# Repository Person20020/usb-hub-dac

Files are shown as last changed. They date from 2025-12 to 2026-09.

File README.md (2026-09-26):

# USB Hub / DAC

> [!NOTE]
> The design has a 22 ohm resistor across the DAC's crystal (I have no clue why I did that) but it should be 1M. It also worked fine just taking the 22 ohm resistor off and leaving it empty.

A simple USB hub with 3 USB C outputs and a built in DAC for a 3.5mm audio output. It uses a SL2.1a USB hub controller and a PCM2902 DAC. 






USB Hub DAC PCB

## PCB
The PCB is designed to be mounted into the case using four M2x6mm screws into the four printed standoffs that use heat set inserts. The mute button is mounted on the top of the PCB and the case has a built in flexing tab that is used as a push button.

usb-hub-dac pcb

Layout



Schematic



## Parts

| Part | Quantity | LCSC # | Price (each) | Total price | Link |
| --- | --- | --- | --- | --- | --- |
| PCM 2902 | 1 | C2651869  | $15.0753 | $15.0753 | [Link](https://www.lcsc.com/product-detail/C2651869.html)  |
| SL2.1a | 1 | C192893 | $0.2259 | $1.13 (5 MOQ) | [Link](https://www.lcsc.com/product-detail/C192893.html) |
| USBLC6-2SC6 | 4 | C2827654  | $0.0387 | $0.39 (10 MOQ) | [Link](https://www.lcsc.com/product-detail/C2827654.html)  |
| PJ-320D 3.5mm TRRS Jack | 1 | C431535 | $0.0483 | $0.48 (10 MOQ) | [Link](https://www.lcsc.com/product-detail/C431535.html) |
| GCT_USB4110 USB C Port | 4 | C5143397  | $1.8037 | $7.21 | [Link](https://www.lcsc.com/product-detail/C5143397.html)  |
| 56k ohm 0805 Resistors | 6 | C2907336  | $0.0014 | $0.14 (100 MOQ)  | [Link](https://www.lcsc.com/product-detail/C2907336.html)  |
| 5.1k ohm 0805 Resistors | 2 | C2930296  | $0.0013 | $0.13 (100 MOQ)  | [Link](https://www.lcsc.com/product-detail/C2930296.html)  |
| 1.5k ohm 0805 Resistors | 1 | C2907216  | $0.0017 | $0.17 (100 MOQ)  | [Link](https://www.lcsc.com/product-detail/C2907216.html)  |
| 2.2 ohm 0805 Resistors | 1 | C2933402  | $0.0023 | $0.23 (100 MOQ)  | [Link](https://www.lcsc.com/product-detail/C2933402.html)  |
| 22 ohm 0805 Resistors | 3 | C2907310  | $0.0014 | $0.014 (100 MOQ) | [Link](https://www.lcsc.com/product-detail/C2907310.html)  |
| 10k ohm 0805 Resistors | 3 | C2930231  | $0.0012 | $0.012 (100 MOQ) | [Link](https://www.lcsc.com/product-detail/C2930231.html)  |
| 10uF Radial D4mm L8mm P1.5mm Capacitors | 4 | C36914040 | $0.0402 | $0.2 (5 MOQ) | [Link](https://www.lcsc.com/product-detail/C36914040.html) |
| 10uF 0805 Capacitors | 6 | C1713 | $0.0088 | $0.18 (20 MOQ) | [Link](https://www.lcsc.com/product-detail/C1713.html) |
| 1uF 0805 Capacitors | 3 | C28323 | $0.0092 | $0.18 (20 MOQ) | [Link](https://www.lcsc.com/product-detail/C28323.html) |
| 10pF 0805 Capacitors | 2 | C41361255 | $0.0045 | $0.45 (100 MOQ)  | [Link](https://www.lcsc.com/product-detail/C41361255.html) |
| 6mm Push Button | 1 | C42416249 | $0.0196 | $0.39 (20 MOQ) | [Link](https://www.lcsc.com/product-detail/C42416249.html) |
| 12 MHz Crystal | 2 | C16369 | $0.0834 | $0.42 (5 MOQ) | [Link](https://www.lcsc.com/product-detail/C16369.html) |

Total cost: \~$26.80 + PCB (\~$2)

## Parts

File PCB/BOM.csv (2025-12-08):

Id | Designator | Footprint | Quantity | Designation | Supplier and ref
1 | U2,U5,U4,U3 | SOT-23-6 | 4 | USBLC6-2SC6
2 | J4,J3,J1,J2 | USB_C_Receptacle_GCT_USB4110 | 4 | USB_C_Receptacle_USB2.0_16P
3 | R4,R6,R2,R3,R7,R5 | R_0805_2012Metric_Pad1.20x1.40mm_HandSolder | 6 | 56k
4 | C12,C7,C8,C11 | CP_Radial_D4.0mm_P1.50mm | 4 | 10uF
5 | C5,C6,C1,C4,C3,C2 | C_0805_2012Metric_Pad1.18x1.45mm_HandSolder | 6 | 10uF
6 | U1 | SSOP-28_5.3x10.2mm_P0.65mm | 1 | PCM2902
7 | R1,R10,R11 | R_0805_2012Metric_Pad1.20x1.40mm_HandSolder | 3 | 10k
8 | C9,C10 | C_0805_2012Metric_Pad1.18x1.45mm_HandSolder | 2 | 10pF
9 | R17 | R_0805_2012Metric_Pad1.20x1.40mm_HandSolder | 1 | 1.5k
10 | J5 | Jack_3.5mm_PJ320D_Horizontal | 1 | AudioJack4
11 | R8,R9 | R_0805_2012Metric_Pad1.20x1.40mm_HandSolder | 2 | 5.1k
12 | R16 | R_0805_2012Metric_Pad1.20x1.40mm_HandSolder | 1 | 2.2
13 | R13,R15,R14 | R_0805_2012Metric_Pad1.20x1.40mm_HandSolder | 3 | 22
14 | C15,C13,C14 | C_0805_2012Metric_Pad1.18x1.45mm_HandSolder | 3 | 1uF
15 | SW1 | SW_PUSH_6mm_H7.3mm | 1 | Mute_button
16 | IC1 | STC_SOP-16_3.9x9.9mm_P1.27mm | 1 | SL2.1A
17 | Y2,Y1 | Crystal_HC49-4H_Vertical | 2 | 12MHz

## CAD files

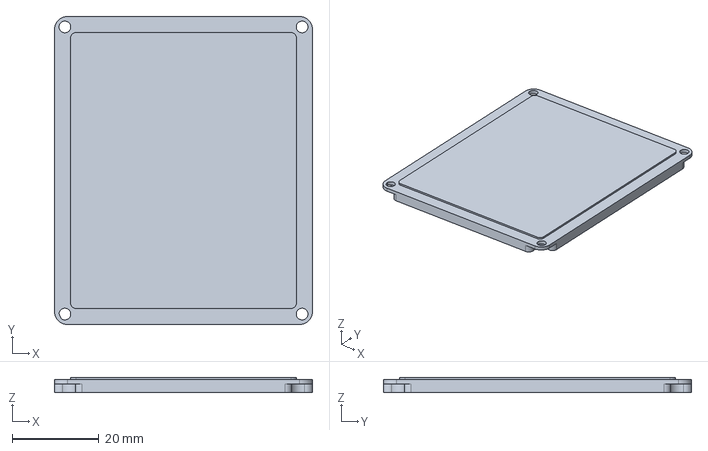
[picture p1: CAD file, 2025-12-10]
CAD/USB Hub DAC Case -- Base.step
59.5 x 71.0 x 3.50 mm

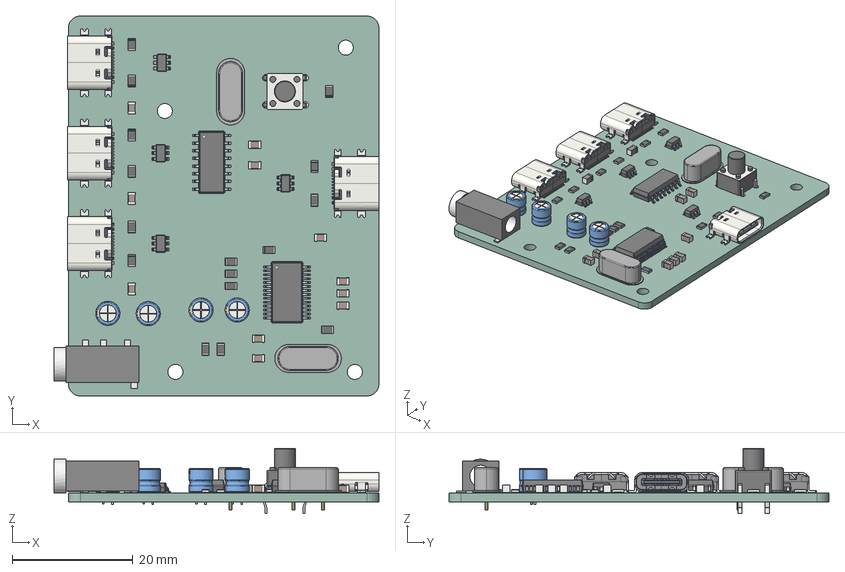
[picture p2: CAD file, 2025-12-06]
PCB/PCB.step
53.9 x 63.0 x 10.8 mm
SOT-23-6 x 4
USB_C_Receptacle_GCT_USB4110-xx-A_16P_TopMnt_Horizontal x 4
R_0805_2012Metric x 16
CP_Radial_D4.0mm_P1.50mm x 4
C_0805_2012Metric x 11
SSOP-28_5.3x10.2mm_P0.65mm
TRRS20153
SW_PUSH_6mm_H7.3mm
SOP-16_4.4x10.4mm_P1.27mm
Crystal_HC49-4H_Vertical x 2
PCB_PCB

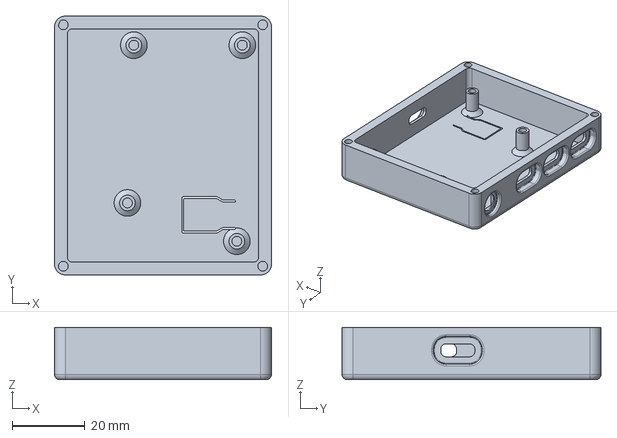
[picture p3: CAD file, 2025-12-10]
CAD/USB Hub DAC Case -- Top.step
59.5 x 71.0 x 14.4 mm

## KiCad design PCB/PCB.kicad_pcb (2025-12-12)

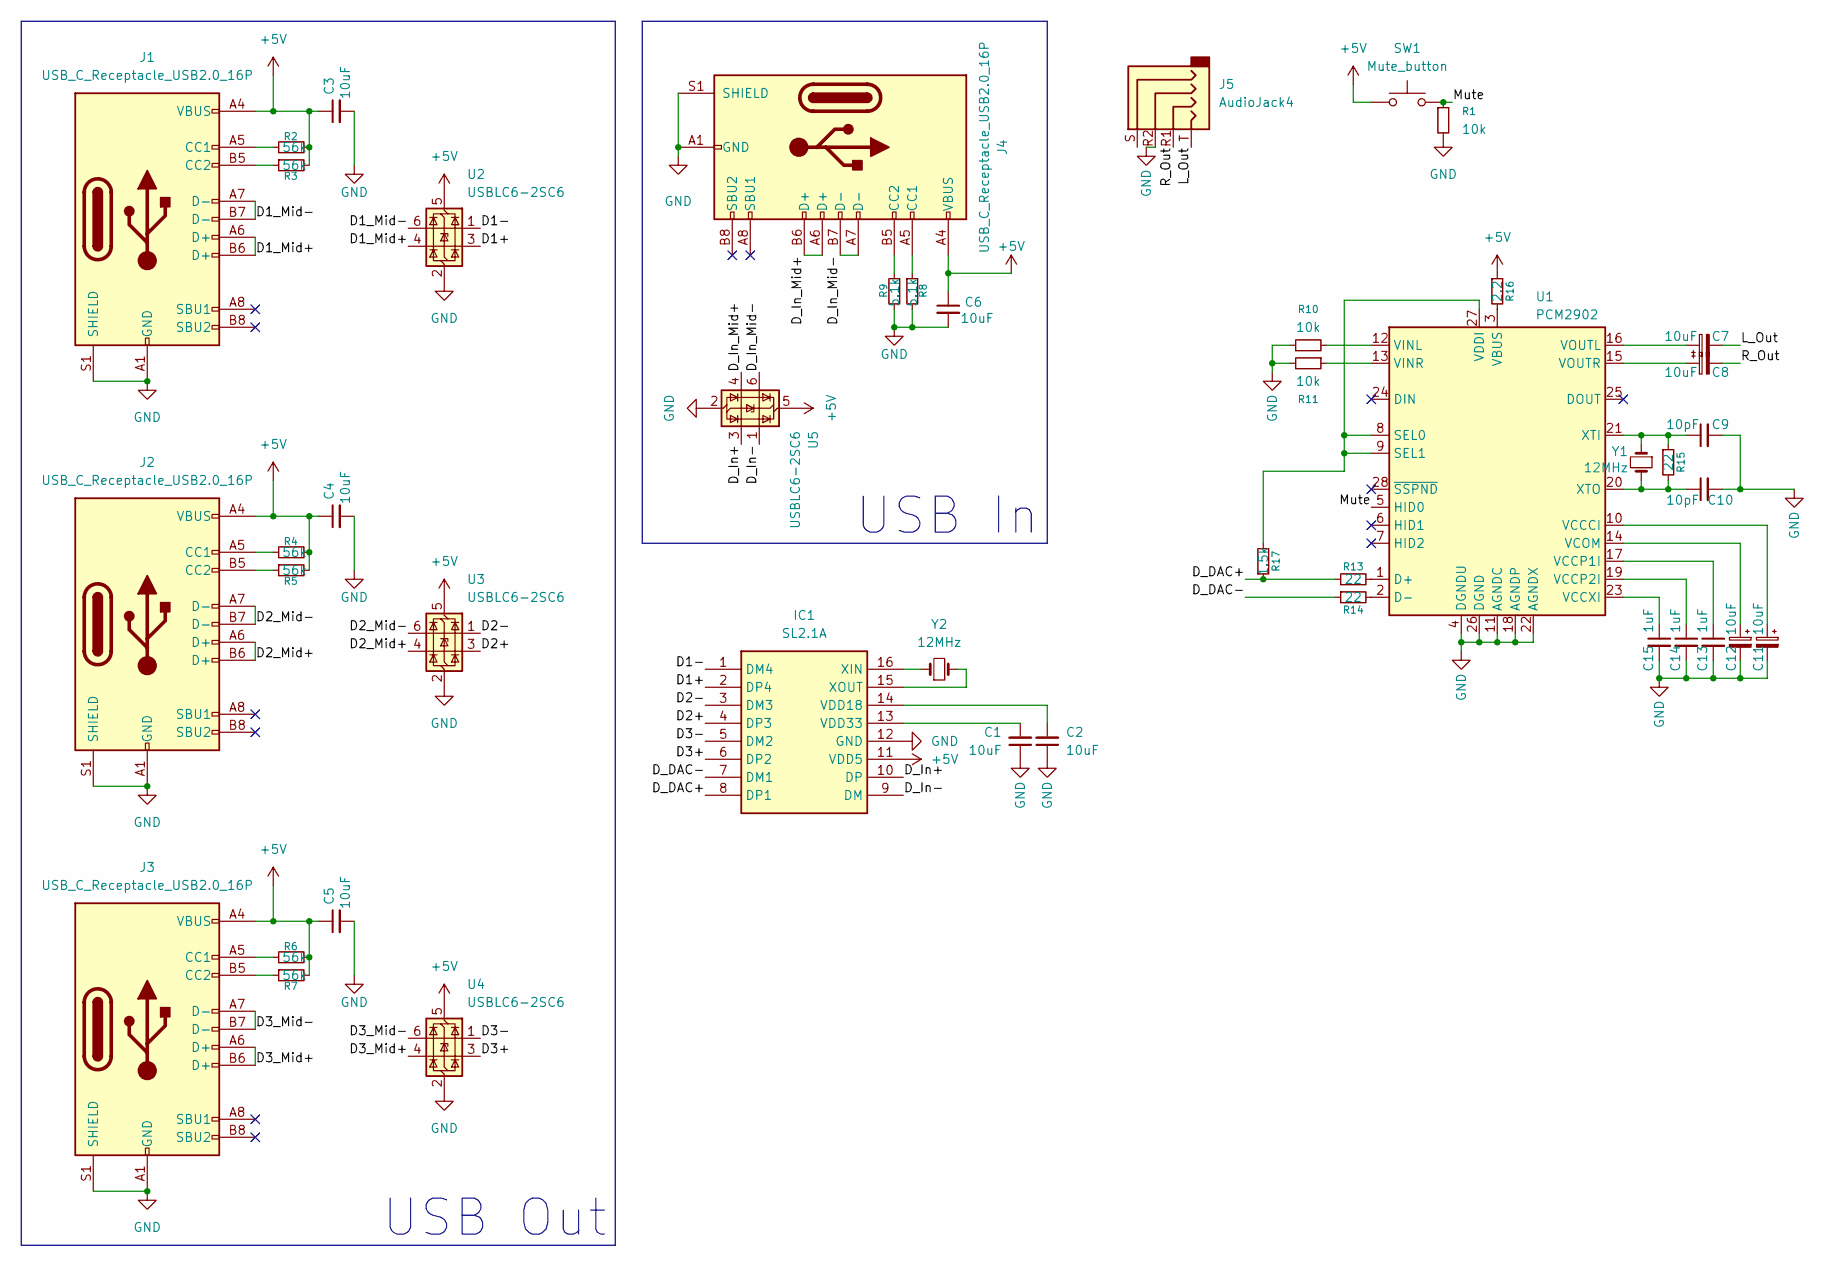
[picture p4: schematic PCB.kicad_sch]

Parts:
C1, C2, C3, C4, C5, C6: 10uF; C_0805_2012Metric_Pad1.18x1.45mm_HandSolder
C7, C8, C11, C12: 10uF; C_Radial_D4.0mm_H7.0mm_P1.50mm
C9, C10: 10pF; C_0805_2012Metric_Pad1.18x1.45mm_HandSolder
C13, C14, C15: 1uF; C_0805_2012Metric_Pad1.18x1.45mm_HandSolder
IC1: SL2.1A; STC_SOP-16_3.9x9.9mm_P1.27mm; Manufacturer_Part_Number SL2.1A
J1, J2, J3, J4: USB_C_Receptacle_USB2.0_16P; USB_C_Receptacle_GCT_USB4110
J5: AudioJack4; Jack_3.5mm_PJ320D_Horizontal
R1, R10, R11: 10k; R_0805_2012Metric_Pad1.20x1.40mm_HandSolder
R2, R3, R4, R5, R6, R7: 56k; R_0805_2012Metric_Pad1.20x1.40mm_HandSolder
R8, R9: 5.1k; R_0805_2012Metric_Pad1.20x1.40mm_HandSolder
R13, R14, R15: 22; R_0805_2012Metric_Pad1.20x1.40mm_HandSolder
R16: 2.2; R_0805_2012Metric_Pad1.20x1.40mm_HandSolder
R17: 1.5k; R_0805_2012Metric_Pad1.20x1.40mm_HandSolder
SW1: Mute_button; SW_PUSH_6mm_H7.3mm
U1: PCM2902; SSOP-28_5.3x10.2mm_P0.65mm
U2, U3, U4, U5: USBLC6-2SC6; SOT-23-6
Y1, Y2: 12MHz; Crystal_HC49-4H_Vertical

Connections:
+5V: C3.1, C4.1, C5.1, C6.1, IC1.11 (VDD5), J1.A4 (VBUS), J1.A9 (VBUS), J1.B4 (VBUS), J1.B9 (VBUS), J2.A4 (VBUS), J2.A9 (VBUS), J2.B4 (VBUS), J2.B9 (VBUS), J3.A4 (VBUS), J3.A9 (VBUS), J3.B4 (VBUS), J3.B9 (VBUS), J4.A4 (VBUS), J4.A9 (VBUS), J4.B4 (VBUS), J4.B9 (VBUS), R2.2, R3.2, R4.2, R5.2, R6.2, R7.2, R16.1, SW1.1, U2.5 (VBUS), U3.5 (VBUS), U4.5 (VBUS), U5.5 (VBUS)
/D1+: IC1.2 (DP4), U2.3 (I/O2)
/D1-: IC1.1 (DM4), U2.1 (I/O1)
/D1_Mid+: J1.A6 (D+), J1.B6 (D+), U2.4 (I/O2)
/D1_Mid-: J1.A7 (D-), J1.B7 (D-), U2.6 (I/O1)
/D2+: IC1.4 (DP3), U3.3 (I/O2)
/D2-: IC1.3 (DM3), U3.1 (I/O1)
/D2_Mid+: J2.A6 (D+), J2.B6 (D+), U3.4 (I/O2)
/D2_Mid-: J2.A7 (D-), J2.B7 (D-), U3.6 (I/O1)
/D3+: IC1.6 (DP2), U4.3 (I/O2)
/D3-: IC1.5 (DM2), U4.1 (I/O1)
/D3_Mid+: J3.A6 (D+), J3.B6 (D+), U4.4 (I/O2)
/D3_Mid-: J3.A7 (D-), J3.B7 (D-), U4.6 (I/O1)
/D_DAC+: IC1.8 (DP1), R13.1, R17.1
/D_DAC-: IC1.7 (DM1), R14.1
/D_In+: IC1.10 (DP), U5.3 (I/O2)
/D_In-: IC1.9 (DM), U5.1 (I/O1)
/D_In_Mid+: J4.A6 (D+), J4.B6 (D+), U5.4 (I/O2)
/D_In_Mid-: J4.A7 (D-), J4.B7 (D-), U5.6 (I/O1)
/L_Out: C7.2, J5.T
/Mute: R1.1, SW1.2, U1.5 (HID0)
/R_Out: C8.2, J5.R1
GND: C1.1, C2.1, C3.2, C4.2, C5.2, C6.2, C9.2, C10.2, C11.2, C12.2, C13.2, C14.2, C15.2, IC1.12 (GND), J1.A1 (GND), J1.A12 (GND), J1.B1 (GND), J1.B12 (GND), J1.S1 (SHIELD), J2.A1 (GND), J2.A12 (GND), J2.B1 (GND), J2.B12 (GND), J2.S1 (SHIELD), J3.A1 (GND), J3.A12 (GND), J3.B1 (GND), J3.B12 (GND), J3.S1 (SHIELD), J4.A1 (GND), J4.A12 (GND), J4.B1 (GND), J4.B12 (GND), J4.S1 (SHIELD), J5.R2, R1.2, R8.2, R9.2, R10.1, R11.2, U1.4 (DGNDU), U1.11 (AGNDC), U1.18 (AGNDP), U1.22 (AGNDX), U1.26 (DGND), U2.2 (GND), U3.2 (GND), U4.2 (GND), U5.2 (GND)
unnamed: C2.2, IC1.14 (VDD18)
unnamed: C1.2, IC1.13 (VDD33)
unnamed: IC1.16 (XIN), Y2.1
unnamed: IC1.15 (XOUT), Y2.2
unnamed: J1.A5 (CC1), R2.1
unnamed: J1.B5 (CC2), R3.1
unnamed: J2.A5 (CC1), R4.1
unnamed: J2.B5 (CC2), R5.1
unnamed: J3.A5 (CC1), R6.1
unnamed: J3.B5 (CC2), R7.1
unnamed: J4.A5 (CC1), R8.1
unnamed: J4.B5 (CC2), R9.1
unnamed: R13.2, U1.1 (D+)
unnamed: R14.2, U1.2 (D-)
unnamed: R17.2, U1.8 (SEL0), U1.9 (SEL1), U1.27 (VDDI)
unnamed: R16.2, U1.3 (VBUS)
unnamed: C11.1, U1.10 (VCCCI)
unnamed: C13.1, U1.17 (VCCP1I)
unnamed: C14.1, U1.19 (VCCP2I)
unnamed: C15.1, U1.23 (VCCXI)
unnamed: C12.1, U1.14 (VCOM)
unnamed: R10.2, U1.12 (VINL)
unnamed: R11.1, U1.13 (VINR)
unnamed: C7.1, U1.16 (VOUTL)
unnamed: C8.1, U1.15 (VOUTR)
unnamed: C9.1, R15.1, U1.21 (XTI), Y1.1
unnamed: C10.1, R15.2, U1.20 (XTO), Y1.2

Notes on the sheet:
USB In
USB Out

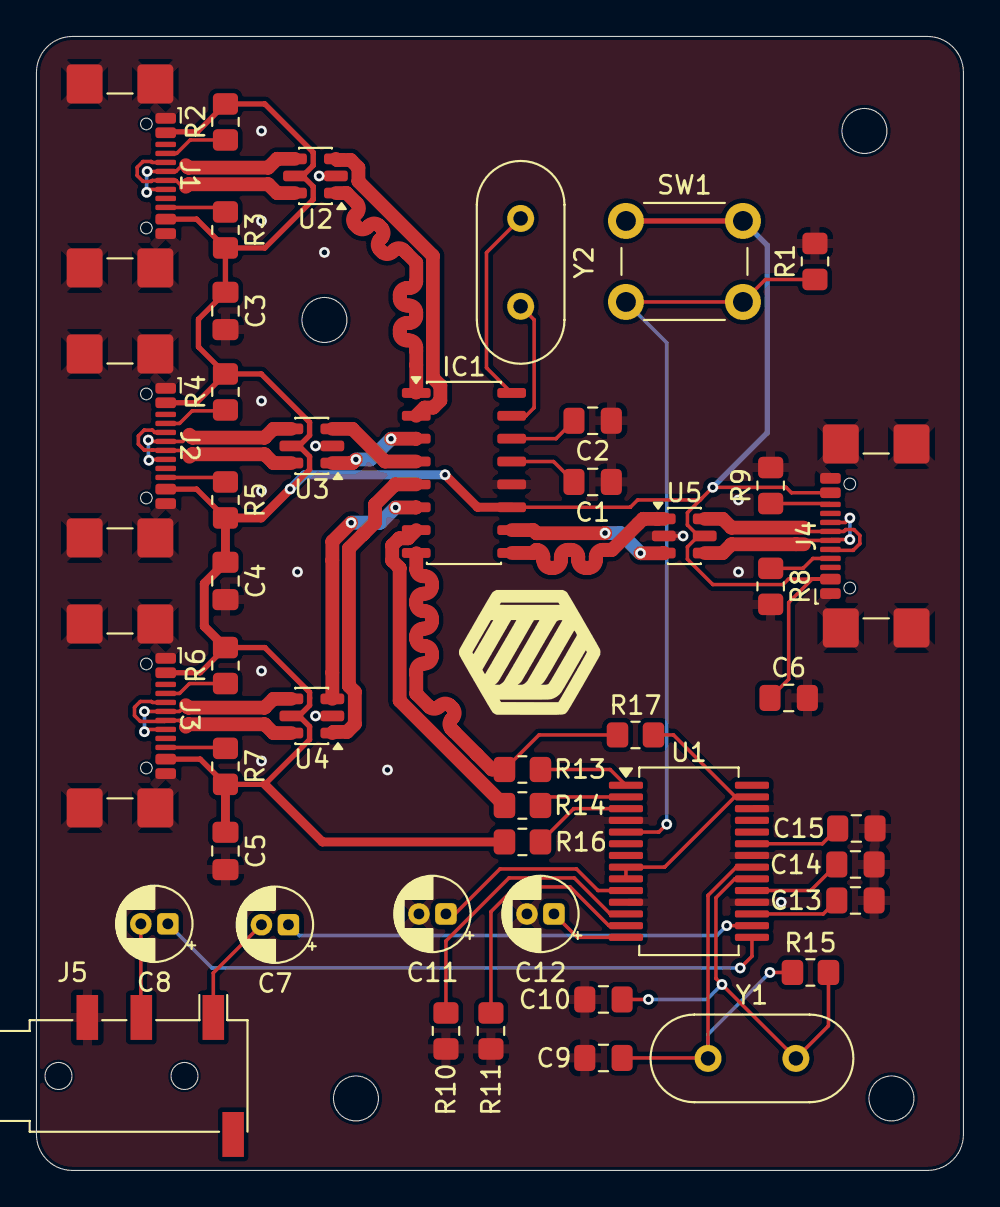
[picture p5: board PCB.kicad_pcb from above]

Board: 2 copper layers, 51.5 x 63.0 mm, 45 parts (0 on the bottom side), 50 nets.

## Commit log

2025-12-03 Wire USB part of schematic and start DAC.
    [PCB.kicad_pcb, PCB.kicad_sch]
2025-12-05 fixed schematic and routed usb hub
    [PCB.kicad_pcb, PCB.kicad_sch]
2025-12-06 finish pcb and generate gerbers
    [PCB-B_Cu.gbr, PCB-B_Mask.gbr, PCB-B_Paste.gbr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]
2025-12-08 add bom.csv and parts list to readme
    [BOM.csv]
2025-12-10 add case and add description to readme
    [USB Hub DAC Case -- Base.step, USB Hub DAC Case -- Top.step]
2025-12-12 add silkscreen and update gerbers
    [PCB-B_Cu.gbr, PCB-B_Mask.gbr, PCB-B_Paste.gbr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]
